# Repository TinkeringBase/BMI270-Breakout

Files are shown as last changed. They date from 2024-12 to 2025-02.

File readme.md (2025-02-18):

[한국어](https://github.com/TinkeringBase/BMI270-Breakout/blob/main/readme-ko.md)
# TinkeringBase BMI270 IMU breakout
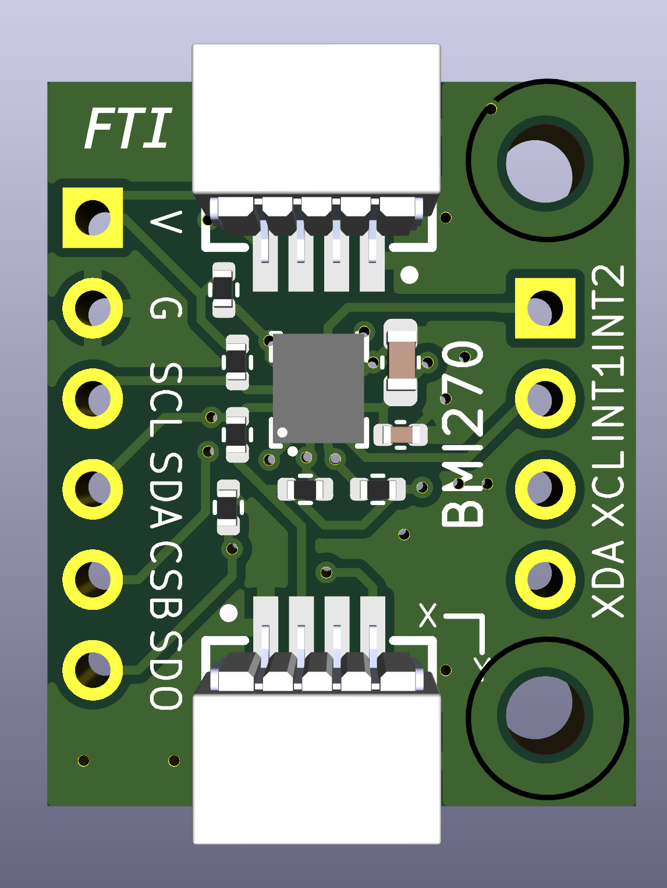
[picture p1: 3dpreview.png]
preview
\
Sensor breakout using Bosch Sensortec's BMI270 6DoF IMU, supports Sparkfun Qwiic system. 

## Specification
Supply Voltage (VDD): 1.71~3.6V \
Logic Low (VIL): 0.3\*VDD max \
Logic High (VIH): 0.7\*VDD min \
Current consumption: around 1mA at performance mode \
for more information, see [BMI270 techdata](https://www.bosch-sensortec.com/products/motion-sensors/imus/bmi270/#technical)

## I2C address
the module uses I2C address 0b1101000 (0x68) by default. to change it to 0b1101001 (0x69), solder the jumper at the back side of the module.

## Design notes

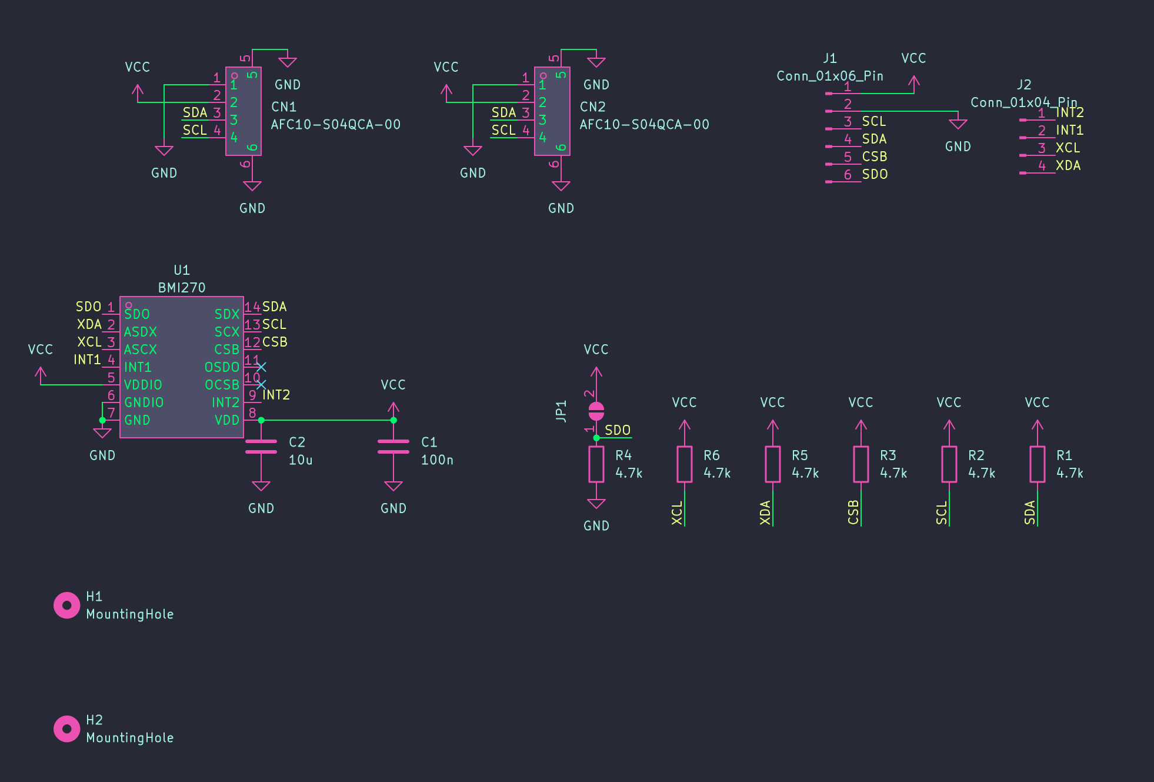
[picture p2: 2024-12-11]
schematic.png

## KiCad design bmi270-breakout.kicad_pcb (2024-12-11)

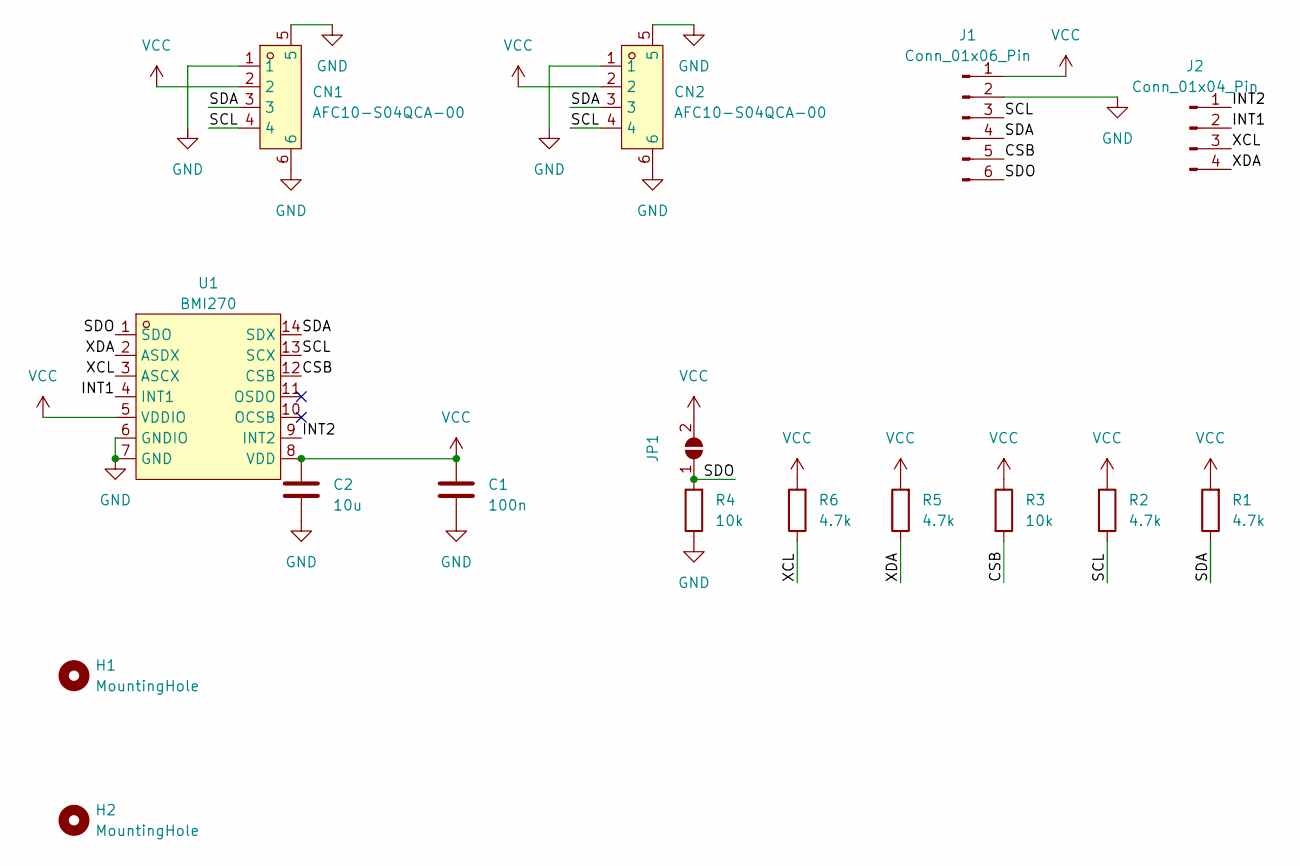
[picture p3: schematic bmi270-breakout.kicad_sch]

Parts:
C1: 100n; C_0402_1005Metric
C2: 10u; C_0603_1608Metric
CN1, CN2: AFC10-S04QCA-00; CONN-SMD_AFC10-S04QCA-00; LCSC Part C2764183
H1, H2: MountingHole; MountingHole_2.2mm_M2
J1: Conn_01x06_Pin; PinHeader_1x06_P2.54mm_Vertical
J2: Conn_01x04_Pin; PinHeader_1x04_P2.54mm_Vertical
JP1: SolderJumper_2_Open; SolderJumper-2_P1.3mm_Open_TrianglePad1.0x1.5mm
R1, R2, R5, R6: 4.7k; R_0402_1005Metric
R3, R4: 10k; R_0402_1005Metric
U1: BMI270; LGA-14_L3.0-W2.5-P0.50-BR; LCSC Part C2836813

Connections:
/CSB: J1.5, R3.2, U1.12 (CSB)
/INT1: J2.2, U1.4 (INT1)
/INT2: J2.1, U1.9 (INT2)
/SCL: CN1.4, CN2.4, J1.3, R2.2, U1.13 (SCX)
/SDA: CN1.3, CN2.3, J1.4, R1.1, U1.14 (SDX)
/SDO: J1.6, JP1.1 (A), R4.2, U1.1 (SDO)
/XCL: J2.3, R6.1, U1.3 (ASCX)
/XDA: J2.4, R5.1, U1.2 (ASDX)
GND: C1.2, C2.2, CN1.1, CN1.5, CN1.6, CN2.1, CN2.5, CN2.6, J1.2, R4.1, U1.6 (GNDIO), U1.7 (GND)
VCC: C1.1, C2.1, CN1.2, CN2.2, J1.1, JP1.2 (B), R1.2, R2.1, R3.1, R5.2, R6.2, U1.5 (VDDIO), U1.8 (VDD)

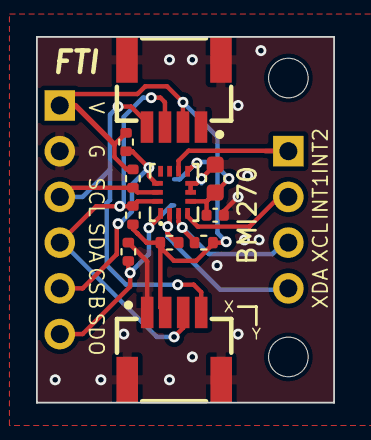
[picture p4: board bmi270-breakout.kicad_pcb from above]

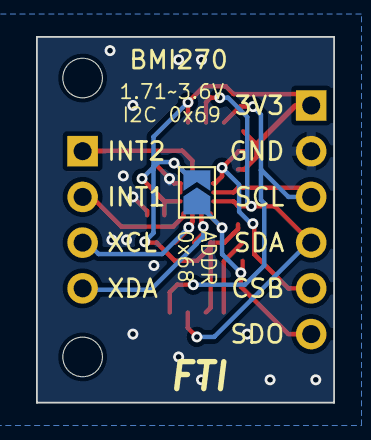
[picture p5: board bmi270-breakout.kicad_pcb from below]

Board: 2 copper layers, 16.5 x 20.3 mm, 16 parts (3 on the bottom side), 10 nets.

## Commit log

2024-01-02 add dimensions mark, preview image files
    [bmi270-breakout.kicad_pcb, bmi270-breakout.step]
2024-01-02 clean up, correct mistakes
    [bmi270-breakout.kicad_pcb]
2024-01-03 forgot pad labels
    [bmi270-breakout.kicad_pcb]
2024-02-28 documentation, migrate to kicad 8, fix address jumper, add branding
    [bmi270-breakout.kicad_pcb, bmi270-breakout.kicad_sch]
2024-04-16 fix qwiic pinout, rework footprint
    [bmi270-breakout.kicad_pcb, bmi270-breakout.kicad_sch]
2024-04-16 allign mounting holes
    [bmi270-breakout.kicad_pcb]
2024-05-10 gitignore and pcb
    [bmi270-breakout.kicad_pcb]
2024-09-19 redo silkscreen
    [bmi270-breakout.kicad_pcb]
2024-12-11 redo layout
    [bmi270-breakout.kicad_pcb, bmi270-breakout.step]
2024-12-11 use higher pullup, refine schematic
    [bmi270-breakout.kicad_pcb, bmi270-breakout.kicad_sch]
